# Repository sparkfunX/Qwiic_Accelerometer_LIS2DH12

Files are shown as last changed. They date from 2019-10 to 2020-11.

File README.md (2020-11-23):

Qwiic Accelerometer LIS2DH12
=======================================

Qwiic Accelerometer LIS2DH12

This MEMS, three axis accelerometer by STMicroelectronics has been outfitted to communicate over Qwiic. The LIS2DH12 is an ultra-low-power highperformance three-axis linear accelerometer belonging to the “femto” family with digital I2C/SPI serial interface standard output.

Repository Contents
-------------------

* **/Hardware** - Eagle design files (.brd, .sch)
* **/Documents** - Documentation
* **/LIS2DH12_test** - Test Script

License Information
-------------------

This product is _**open source**_! 

Please review the LICENSE.md file for license information. 

If you have any questions or concerns on licensing, please contact technical support on our [SparkFun forums](https://forum.sparkfun.com/viewforum.php?f=152).

Distributed as-is; no warranty is given.

- Your friends at SparkFun.

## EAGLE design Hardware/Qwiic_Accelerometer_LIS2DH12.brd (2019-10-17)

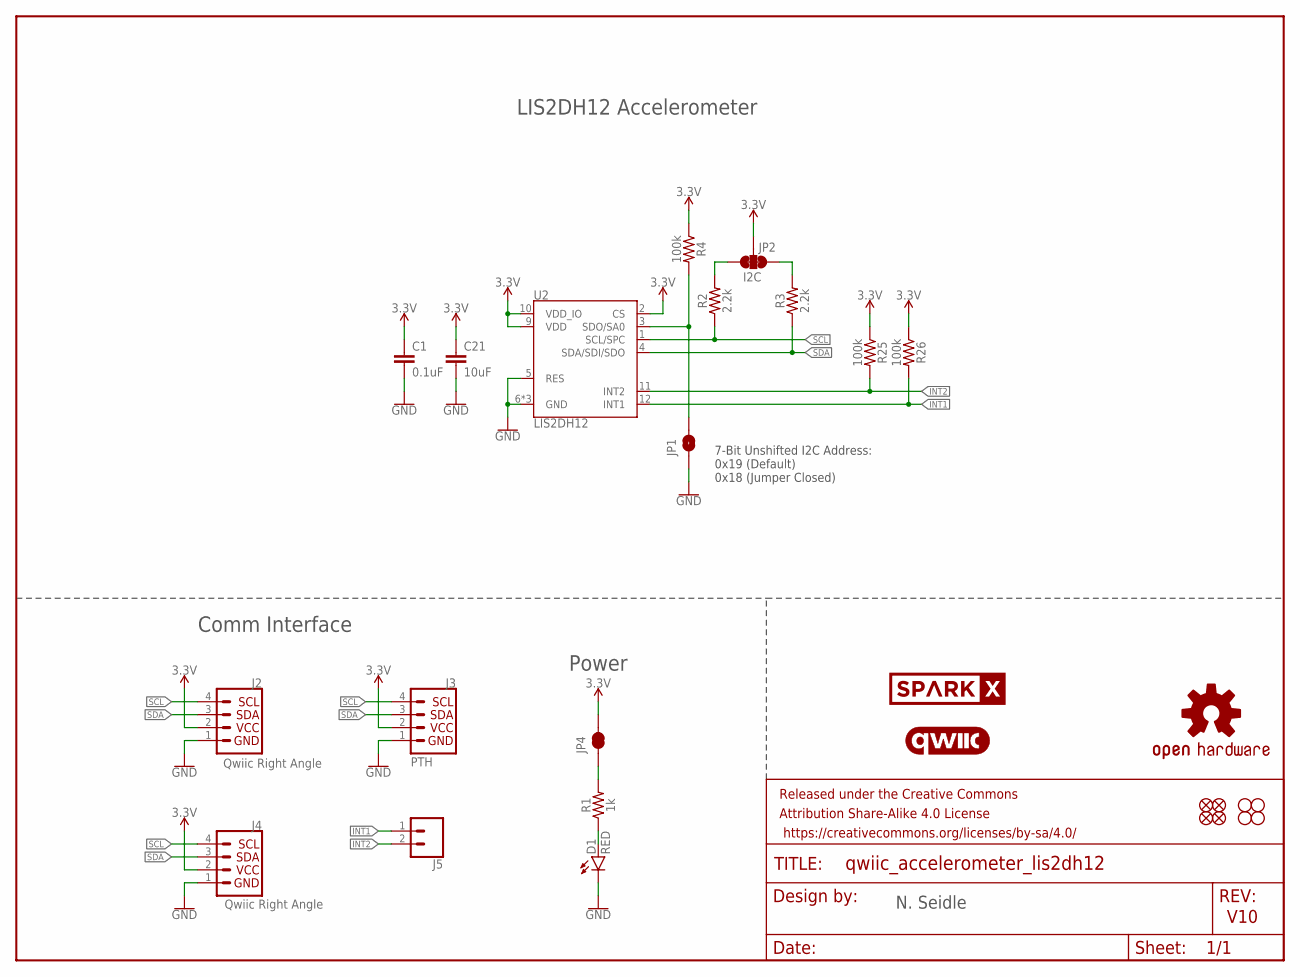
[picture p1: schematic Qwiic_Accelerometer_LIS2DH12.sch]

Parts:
C1: 0.1uF; 0603
C21: 10uF; 0603
D1: RED; LED-0603
FD1, FD2, FD3, FD4: FIDUCIALUFIDUCIAL; FIDUCIAL-MICRO
FRAME1: FRAME-LETTER; CREATIVE_COMMONS
H1, H2, H3, H4: STAND-OFF
J2, J4: Qwiic Right Angle; JST04_1MM_RA
J3: PTH; 1X04_NO_SILK
J5: CONN_021X02_NO_SILK; 1X02_NO_SILK
JP1: JUMPER-SMT_2_NO_SILK; SMT-JUMPER_2_NO_SILK
JP2: I2C; SMT-JUMPER_3_2-NC_TRACE_SILK
JP4: JUMPER-SMT_2_NC_TRACE_SILK; SMT-JUMPER_2_NC_TRACE_SILK
LOGO1: OSHW-LOGOMINI; OSHW-LOGO-MINI
LOGO4: QWIIC_LOGO_CONNECTOR; QWIIC_5.5MM
R1: 1k; 0603
R2, R3: 2.2k; 0603
R4, R25, R26: 100k; 0603
U2: LIS2DH12; LGA-12-LISDH12
U$30: SPARKX-LOGO4; SPARKX-MEDIUM

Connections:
3.3V: C1.1, C21.1, J2.2, J3.2, J4.2, JP2.2, JP4.2, R4.1, R25.1, R26.1, U2.2 (CS), U2.9 (VDD), U2.10 (VDD_IO)
GND: C1.2, C21.2, D1.C, J2.1, J3.1, J4.1, JP1.1, U2.5 (RES), U2.6 (GND), U2.7 (GND), U2.8 (GND)
INT1: J5.1, R26.2, U2.12 (INT1)
INT2: J5.2, R25.2, U2.11 (INT2)
unnamed: JP4.1, R1.2
unnamed: JP2.1, R3.2
unnamed: JP2.3, R2.2
unnamed: JP1.2, R4.2, U2.3 (SDO/SA0)
unnamed: D1.A, R1.1
SCL: J2.4, J3.4, J4.4, R2.1, U2.1 (SCL/SPC)
SDA: J2.3, J3.3, J4.3, R3.1, U2.4 (SDA/SDI/SDO)

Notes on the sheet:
V10
N. Seidle
LIS2DH12 Accelerometer
Comm Interface
Power
7-Bit Unshifted I2C Address: 0x19 (Default) 0x18 (Jumper Closed)

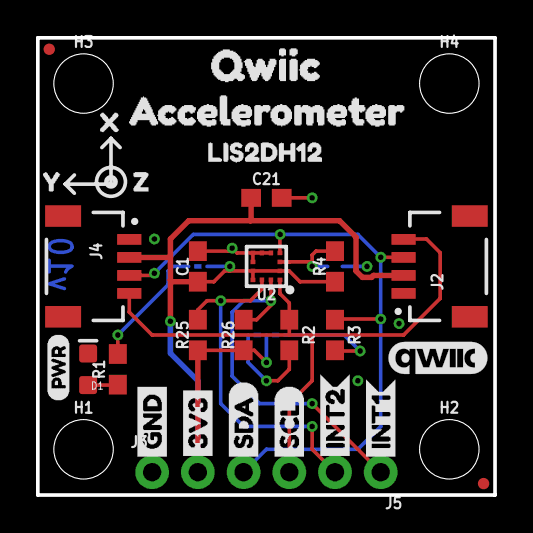
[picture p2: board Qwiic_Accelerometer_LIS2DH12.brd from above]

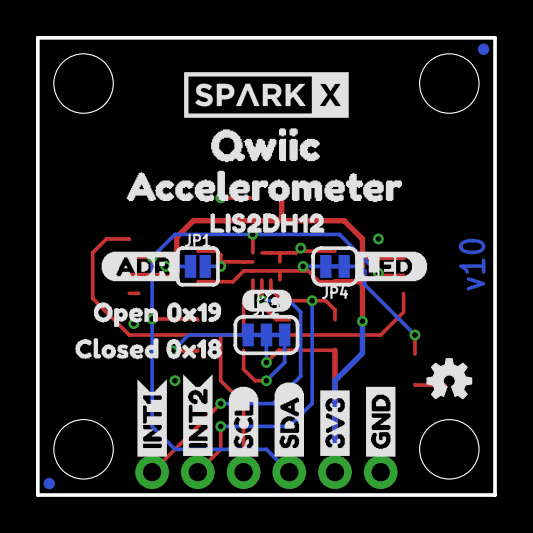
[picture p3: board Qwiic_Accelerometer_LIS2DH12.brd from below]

Board: 2 copper layers, 25.4 x 25.4 mm, 58 parts (23 on the bottom side), 11 nets.

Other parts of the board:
U$1, U$4: SDA-[)
U$2: X0
U$3, U$5: SCL-[)
U$6, U$7: 3V3-04
U$8, U$9: GND-04
U$10, U$27: ACCELEROMETER2
U$11, U$12: INT13
U$13, U$15: INT24
U$14, U$22: QWIIC2
U$16: 0X183
U$17, U$28: LIS2DH120
U$18: PWR-()-03
U$19: I_SUPER2_C-()-03
U$20: Y1
U$21: Z2
U$23: 0X192
U$24: ADR1
U$25: CLOSED4
U$26: OPEN5
U$29: LED7

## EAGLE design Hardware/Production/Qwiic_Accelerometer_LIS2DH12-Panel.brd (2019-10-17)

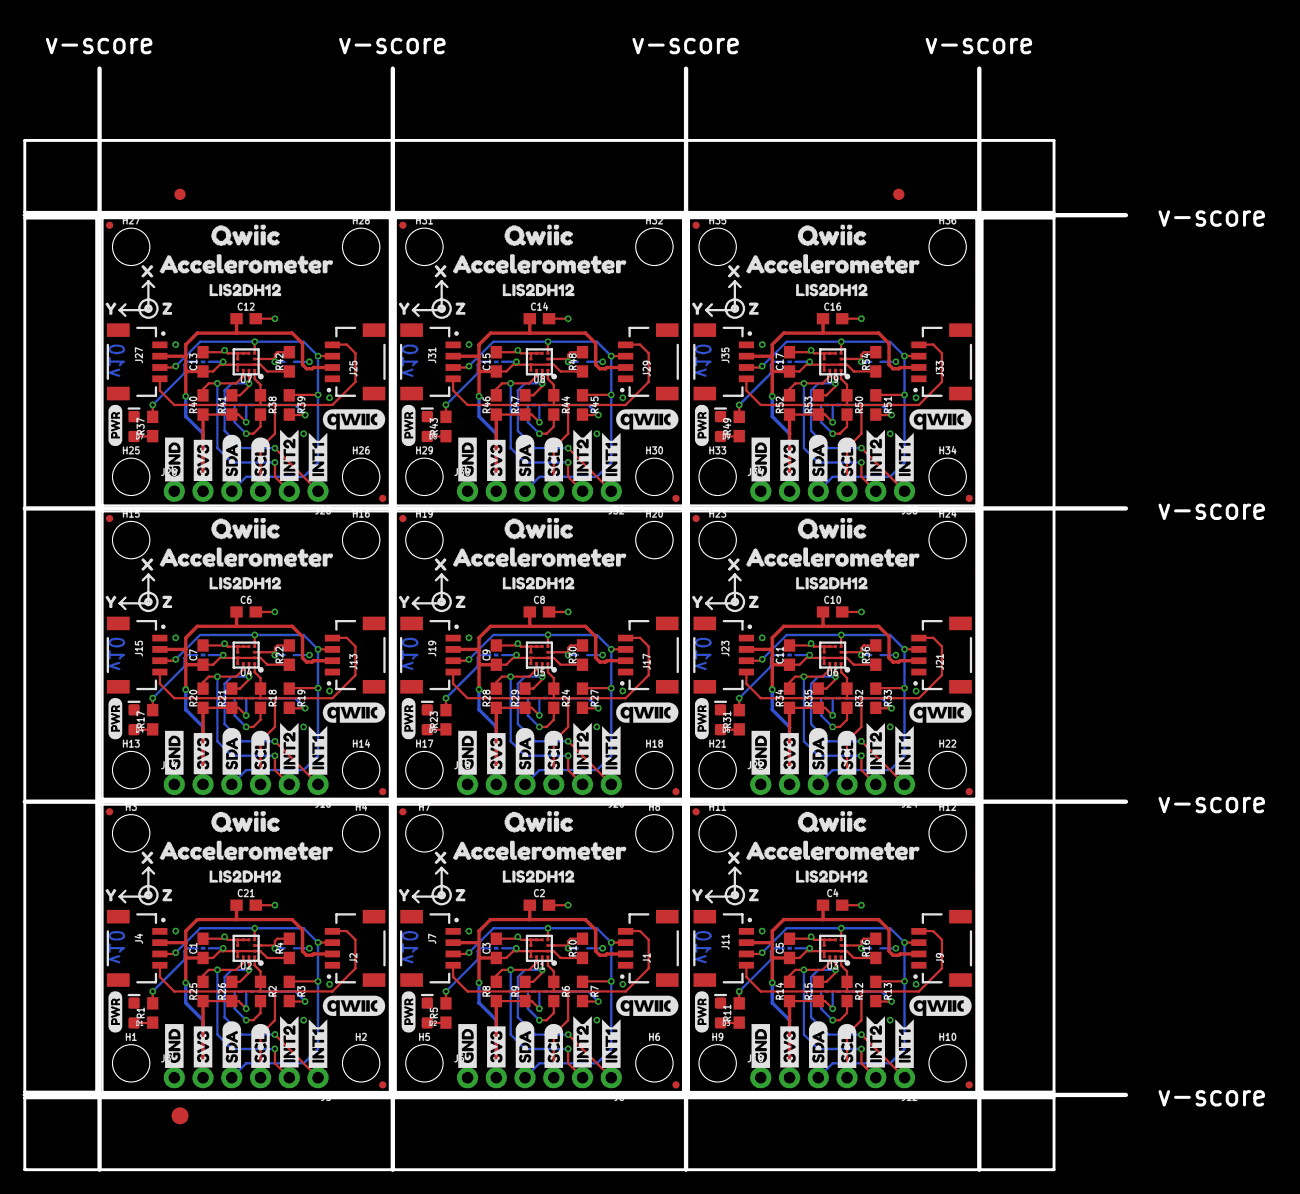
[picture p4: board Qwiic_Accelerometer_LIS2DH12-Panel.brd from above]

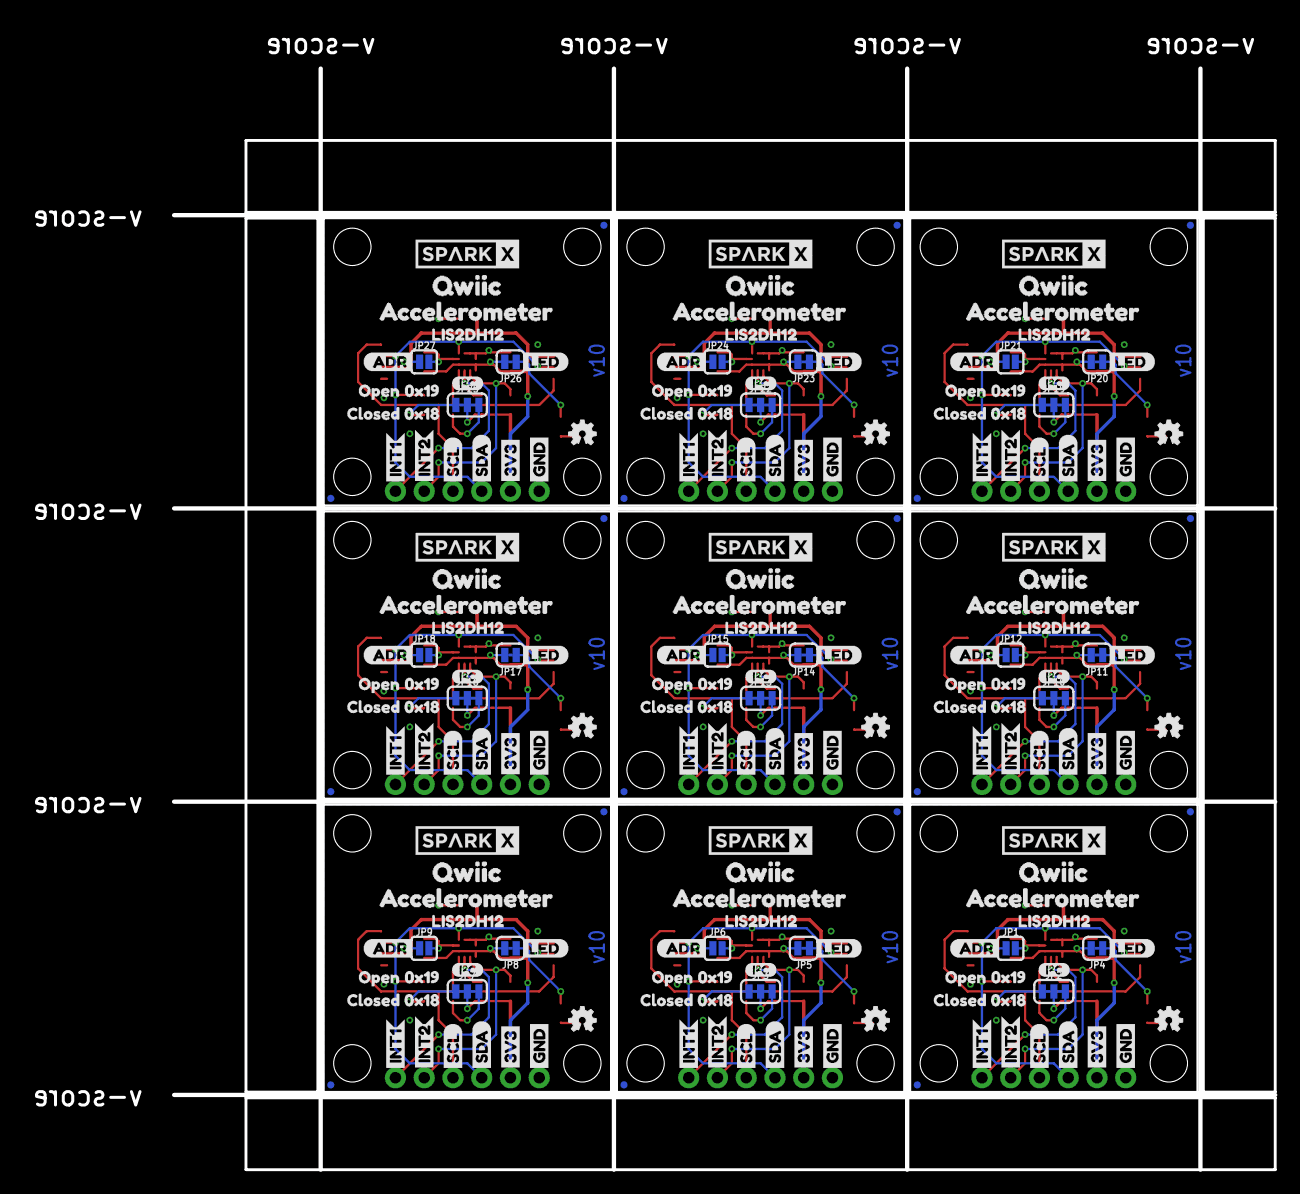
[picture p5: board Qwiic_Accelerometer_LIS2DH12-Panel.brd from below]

Board: 2 copper layers, 97.3 x 97.3 mm, 516 parts (207 on the bottom side), 99 nets.

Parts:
C1, C3, C5, C7, C9, C11, C13, C15, C17: 0.1uF; 0603
C2, C4, C6, C8, C10, C12, C14, C16, C21: 10uF; 0603
D1, D2, D3, D4, D5, D6, D7, D8, D9: RED; LED-0603
E$1, E$2: FIDUCIAL-1X2
E$3: FIDUCIAL-1.5X3
FD1, FD2, FD3, FD4, FD5, FD6, FD7, FD8, FD9, FD10, FD11, FD12, FD13, FD14, FD15, FD16, FD17, FD18, FD19, FD20, FD21, FD22, FD23, FD24, FD25, FD26, FD27, FD28, FD29, FD30, FD31, FD32, FD33, FD34, FD35, FD36: FIDUCIALUFIDUCIAL; FIDUCIAL-MICRO
H1, H2, H3, H4, H5, H6, H7, H8, H9, H10, H11, H12, H13, H14, H15, H16, H17, H18, H19, H20, H21, H22, H23, H24, H25, H26, H27, H28, H29, H30, H31, H32, H33, H34, H35, H36: STAND-OFF
J1, J2, J4, J7, J9, J11, J13, J15, J17, J19, J21, J23, J25, J27, J29, J31, J33, J35: Qwiic Right Angle; JST04_1MM_RA
J3, J6, J10, J14, J18, J22, J26, J30, J34: PTH; 1X04_NO_SILK
J5, J8, J12, J16, J20, J24, J28, J32, J36: 1X02_NO_SILK
JP1, JP6, JP9, JP12, JP15, JP18, JP21, JP24, JP27: SMT-JUMPER_2_NO_SILK
JP2, JP3, JP7, JP10, JP13, JP16, JP19, JP22, JP25: I2C; SMT-JUMPER_3_2-NC_TRACE_SILK
JP4, JP5, JP8, JP11, JP14, JP17, JP20, JP23, JP26: SMT-JUMPER_2_NC_TRACE_SILK
LOGO1, LOGO2, LOGO5, LOGO7, LOGO9, LOGO11, LOGO13, LOGO15, LOGO17: OSHW-LOGOMINI; OSHW-LOGO-MINI
LOGO3, LOGO4, LOGO6, LOGO8, LOGO10, LOGO12, LOGO14, LOGO16, LOGO18: QWIIC_LOGO_CONNECTOR; QWIIC_5.5MM
R1, R5, R11, R17, R23, R31, R37, R43, R49: 1k; 0603
R2, R3, R6, R7, R12, R13, R18, R19, R24, R27, R32, R33, R38, R39, R44, R45, R50, R51: 2.2k; 0603
R4, R8, R9, R10, R14, R15, R16, R20, R21, R22, R25, R26, R28, R29, R30, R34, R35, R36, R40, R41, R42, R46, R47, R48, R52, R53, R54: 100k; 0603
U1, U2, U3, U4, U5, U6, U7, U8, U9: LIS2DH12; LGA-12-LISDH12
U$1, U$4, U$31, U$33, U$61, U$63, U$91, U$93, U$121, U$123, U$151, U$153, U$181, U$183, U$211, U$213, U$241, U$243: SDA-[)
U$2, U$49, U$79, U$109, U$139, U$169, U$199, U$229, U$259: X0
U$3, U$5, U$32, U$34, U$62, U$64, U$92, U$94, U$122, U$124, U$152, U$154, U$182, U$184, U$212, U$214, U$242, U$244: SCL-[)
U$6, U$7, U$35, U$36, U$65, U$66, U$95, U$96, U$125, U$126, U$155, U$156, U$185, U$186, U$215, U$216, U$245, U$246: 3V3-04
U$8, U$9, U$37, U$38, U$67, U$68, U$97, U$98, U$127, U$128, U$157, U$158, U$187, U$188, U$217, U$218, U$247, U$248: GND-04
U$10, U$27, U$43, U$56, U$73, U$86, U$103, U$116, U$133, U$146, U$163, U$176, U$193, U$206, U$223, U$236, U$253, U$266: ACCELEROMETER2
U$11, U$12, U$44, U$45, U$74, U$75, U$104, U$105, U$134, U$135, U$164, U$165, U$194, U$195, U$224, U$225, U$254, U$255: INT13
U$13, U$15, U$46, U$47, U$76, U$77, U$106, U$107, U$136, U$137, U$166, U$167, U$196, U$197, U$226, U$227, U$256, U$257: INT24
U$14, U$22, U$40, U$42, U$70, U$72, U$100, U$102, U$130, U$132, U$160, U$162, U$190, U$192, U$220, U$222, U$250, U$252: QWIIC2
U$16, U$52, U$82, U$112, U$142, U$172, U$202, U$232, U$262: 0X183
U$17, U$28, U$48, U$57, U$78, U$87, U$108, U$117, U$138, U$147, U$168, U$177, U$198, U$207, U$228, U$237, U$258, U$267: LIS2DH120
U$18, U$39, U$69, U$99, U$129, U$159, U$189, U$219, U$249: PWR-()-03
U$19, U$41, U$71, U$101, U$131, U$161, U$191, U$221, U$251: I_SUPER2_C-()-03
U$20, U$50, U$80, U$110, U$140, U$170, U$200, U$230, U$260: Y1
U$21, U$51, U$81, U$111, U$141, U$171, U$201, U$231, U$261: Z2
U$23, U$53, U$83, U$113, U$143, U$173, U$203, U$233, U$263: 0X192
U$24, U$54, U$84, U$114, U$144, U$174, U$204, U$234, U$264: ADR1
U$25, U$55, U$85, U$115, U$145, U$175, U$205, U$235, U$265: CLOSED4
U$26, U$59, U$89, U$119, U$149, U$179, U$209, U$239, U$269: OPEN5
U$29, U$58, U$88, U$118, U$148, U$178, U$208, U$238, U$268: LED7
U$30, U$60, U$90, U$120, U$150, U$180, U$210, U$240, U$270: SPARKX-LOGO4; SPARKX-MEDIUM

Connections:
3.3V: C1.1, C21.1, J2.2, J3.2, J4.2, JP2.2, JP4.2, R4.1, R25.1, R26.1, U2.2, U2.9, U2.10
3.3V1: C2.1, C3.1, J1.2, J6.2, J7.2, JP3.2, JP5.2, R8.1, R9.1, R10.1, U1.2, U1.9, U1.10
3.3V2: C4.1, C5.1, J9.2, J10.2, J11.2, JP7.2, JP8.2, R14.1, R15.1, R16.1, U3.2, U3.9, U3.10
3.3V3: C6.1, C7.1, J13.2, J14.2, J15.2, JP10.2, JP11.2, R20.1, R21.1, R22.1, U4.2, U4.9, U4.10
3.3V4: C8.1, C9.1, J17.2, J18.2, J19.2, JP13.2, JP14.2, R28.1, R29.1, R30.1, U5.2, U5.9, U5.10
3.3V5: C10.1, C11.1, J21.2, J22.2, J23.2, JP16.2, JP17.2, R34.1, R35.1, R36.1, U6.2, U6.9, U6.10
3.3V6: C12.1, C13.1, J25.2, J26.2, J27.2, JP19.2, JP20.2, R40.1, R41.1, R42.1, U7.2, U7.9, U7.10
3.3V7: C14.1, C15.1, J29.2, J30.2, J31.2, JP22.2, JP23.2, R46.1, R47.1, R48.1, U8.2, U8.9, U8.10
3.3V8: C16.1, C17.1, J33.2, J34.2, J35.2, JP25.2, JP26.2, R52.1, R53.1, R54.1, U9.2, U9.9, U9.10
GND: C1.2, C21.2, D1.C, J2.1, J3.1, J4.1, JP1.1, U2.5, U2.6, U2.7, U2.8
GND1: C2.2, C3.2, D2.C, J1.1, J6.1, J7.1, JP6.1, U1.5, U1.6, U1.7, U1.8
GND2: C4.2, C5.2, D3.C, J9.1, J10.1, J11.1, JP9.1, U3.5, U3.6, U3.7, U3.8
GND3: C6.2, C7.2, D4.C, J13.1, J14.1, J15.1, JP12.1, U4.5, U4.6, U4.7, U4.8
GND4: C8.2, C9.2, D5.C, J17.1, J18.1, J19.1, JP15.1, U5.5, U5.6, U5.7, U5.8
GND5: C10.2, C11.2, D6.C, J21.1, J22.1, J23.1, JP18.1, U6.5, U6.6, U6.7, U6.8
GND6: C12.2, C13.2, D7.C, J25.1, J26.1, J27.1, JP21.1, U7.5, U7.6, U7.7, U7.8
GND7: C14.2, C15.2, D8.C, J29.1, J30.1, J31.1, JP24.1, U8.5, U8.6, U8.7, U8.8
GND8: C16.2, C17.2, D9.C, J33.1, J34.1, J35.1, JP27.1, U9.5, U9.6, U9.7, U9.8
INT1: J5.1, R26.2, U2.12
INT2: J5.2, R25.2, U2.11
INT3: J8.1, R9.2, U1.12
INT4: J8.2, R8.2, U1.11
INT5: J12.1, R15.2, U3.12
INT6: J12.2, R14.2, U3.11
INT7: J16.1, R21.2, U4.12
INT8: J16.2, R20.2, U4.11
INT9: J20.1, R29.2, U5.12
INT10: J20.2, R28.2, U5.11
INT11: J24.1, R35.2, U6.12
INT12: J24.2, R34.2, U6.11
INT13: J28.1, R41.2, U7.12
INT14: J28.2, R40.2, U7.11
INT15: J32.1, R47.2, U8.12
INT16: J32.2, R46.2, U8.11
INT17: J36.1, R53.2, U9.12
INT18: J36.2, R52.2, U9.11
unnamed: JP4.1, R1.2
unnamed: JP2.1, R3.2
unnamed: JP2.3, R2.2
unnamed: JP1.2, R4.2, U2.3
unnamed: D2.A, R5.1
unnamed: JP3.1, R7.2
unnamed: JP3.3, R6.2
unnamed: JP5.1, R5.2
unnamed: JP6.2, R10.2, U1.3
unnamed: D1.A, R1.1
unnamed: D3.A, R11.1
unnamed: JP7.1, R13.2
unnamed: JP7.3, R12.2
unnamed: JP8.1, R11.2
unnamed: JP9.2, R16.2, U3.3
unnamed: D4.A, R17.1
unnamed: JP10.1, R19.2
unnamed: JP10.3, R18.2
unnamed: JP11.1, R17.2
unnamed: JP12.2, R22.2, U4.3
unnamed: D5.A, R23.1
unnamed: JP13.1, R27.2
unnamed: JP13.3, R24.2
unnamed: JP14.1, R23.2
unnamed: JP15.2, R30.2, U5.3
unnamed: D6.A, R31.1
unnamed: JP16.1, R33.2
unnamed: JP16.3, R32.2
unnamed: JP17.1, R31.2
unnamed: JP18.2, R36.2, U6.3
unnamed: D7.A, R37.1
unnamed: JP19.1, R39.2
unnamed: JP19.3, R38.2
unnamed: JP20.1, R37.2
unnamed: JP21.2, R42.2, U7.3
unnamed: D8.A, R43.1
unnamed: JP22.1, R45.2
unnamed: JP22.3, R44.2
unnamed: JP23.1, R43.2
unnamed: JP24.2, R48.2, U8.3
unnamed: D9.A, R49.1
unnamed: JP25.1, R51.2
unnamed: JP25.3, R50.2
unnamed: JP26.1, R49.2
unnamed: JP27.2, R54.2, U9.3
SCL: J2.4, J3.4, J4.4, R2.1, U2.1
SCL1: J1.4, J6.4, J7.4, R6.1, U1.1
SCL2: J9.4, J10.4, J11.4, R12.1, U3.1
SCL3: J13.4, J14.4, J15.4, R18.1, U4.1
SCL4: J17.4, J18.4, J19.4, R24.1, U5.1
SCL5: J21.4, J22.4, J23.4, R32.1, U6.1
SCL6: J25.4, J26.4, J27.4, R38.1, U7.1
SCL7: J29.4, J30.4, J31.4, R44.1, U8.1
SCL8: J33.4, J34.4, J35.4, R50.1, U9.1
SDA: J2.3, J3.3, J4.3, R3.1, U2.4
SDA1: J1.3, J6.3, J7.3, R7.1, U1.4
SDA2: J9.3, J10.3, J11.3, R13.1, U3.4
SDA3: J13.3, J14.3, J15.3, R19.1, U4.4
SDA4: J17.3, J18.3, J19.3, R27.1, U5.4
SDA5: J21.3, J22.3, J23.3, R33.1, U6.4
SDA6: J25.3, J26.3, J27.3, R39.1, U7.4
SDA7: J29.3, J30.3, J31.3, R45.1, U8.4
SDA8: J33.3, J34.3, J35.3, R51.1, U9.4

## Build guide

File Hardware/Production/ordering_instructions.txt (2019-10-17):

panel size, 91x91mm
PCB thickness, 1.6mm
number of layers, 2
soldermask color, Black
silkscreen color, White
oz copper, 1oz
finish, HASL lead free
stencils, top+bottom
pcs per panel, 9
min trace width, 0.203200mm / 0.008000in
min drill size, 0.304800mm / 0.012000in

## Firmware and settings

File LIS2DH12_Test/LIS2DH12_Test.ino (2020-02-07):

/*
  Reading and controlling the very low power LIS2DH12
  Author: Nathan Seidle
  Created: Septempter 18th, 2019
  License: This code is Lemonadeware; do whatever you want with this code.
  If you see me (or any other SparkFun employee) at the
  local, and you've found our code helpful, please buy us a round!

  This example demonstrates how to read XYZ from the LIS2DH12.

  Feel like supporting open source hardware?
  Buy a board from SparkFun!
  Edge: https://www.sparkfun.com/products/15170
  Edge 2: https://www.sparkfun.com/products/15420
  Qwiic LIS2DH12 Breakout: https://www.sparkfun.com/products/15760

  Hardware Connections:
  Plug a Qwiic cable into the Qwiic Accelerometer RedBoard Qwiic or BlackBoard
  If you don't have a platform with a Qwiic connection use the SparkFun Qwiic Breadboard Jumper (https://www.sparkfun.com/products/14425)
  Open the serial monitor at 115200 baud to see the output
*/

#include <Wire.h>

#include "SparkFun_LIS2DH12.h" //Click here to get the library: http://librarymanager/All#SparkFun_LIS2DH12
SPARKFUN_LIS2DH12 accel;       //Create instance

const int LED = 13;

void setup()
{
  Serial.begin(115200);
  Serial.println("SparkFun Accel Example");

  Wire.begin();

  pinMode(LED, OUTPUT);
}

void loop()
{
  if (accel.begin() == true) {
    //Print accel values only if new data is available
    if (accel.available())
    {
      digitalWrite(LED, HIGH);
      
      float accelX = accel.getX();
      float accelY = accel.getY();
      float accelZ = accel.getZ();
      float tempC = accel.getTemperature();

      Serial.print("Acc [mg]: ");
      Serial.print(accelX, 1);
      Serial.print(" x, ");
      Serial.print(accelY, 1);
      Serial.print(" y, ");
      Serial.print(accelZ, 1);
      Serial.print(" z, ");
      Serial.print(tempC, 1);
      Serial.print("C");
      Serial.println();

    }
  } else {
    digitalWrite(LED, LOW);
    Serial.println("Nothing detected.");
  }
}

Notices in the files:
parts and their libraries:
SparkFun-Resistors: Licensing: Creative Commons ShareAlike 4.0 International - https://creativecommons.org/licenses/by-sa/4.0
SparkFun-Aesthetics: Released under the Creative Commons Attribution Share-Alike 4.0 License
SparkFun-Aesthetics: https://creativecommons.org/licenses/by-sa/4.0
